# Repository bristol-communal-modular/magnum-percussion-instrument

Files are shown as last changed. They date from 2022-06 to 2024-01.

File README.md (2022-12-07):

# The Magnum Percussion Instrument

A drum synthesiser created by members of the Bristol Communal Modular group

## Description

Mostly combining bits from other open source schematics.

Specifically :-

* The Clacktronics Star Synare 3
* The Befaco Kickall

Many thanks to the people that designed those and made them open.

## Building

In the *build* folder there's an html BOM file, along with a CSV file that has part numbers for most components. Read the build.md file in there for more information. If you're reading this on GitHub and are unsure how to easily get these files, then [use this link](https://github.com/bristol-communal-modular/magnum-percussion-instrument/archive/refs/heads/main.zip)

## Spec

*Finish this*

### Power

30mA on +12v
30mA on -12v

Doesn't use 5v

## Contact

Come down the Bristol Hackspace on a Tuesday night to say hello.

## License

The Magnum Percussion Instrument is shared under an [Attribution-NonCommercial-ShareAlike 4.0 International License](https://creativecommons.org/licenses/by-nc-sa/4.0/)

This means that you can share the info here around, and transform or build upon the circuits and designs in here, as long as you share anything you do under the same license and give BCM a shout-out.

We don't license this for commercial purposes, but if you'd like to run a workshop with the Magnum or some variation of it, just get in contact and we can sort something out.
If you want to build a couple to sell to your mates then we're pretty fine with that as well.

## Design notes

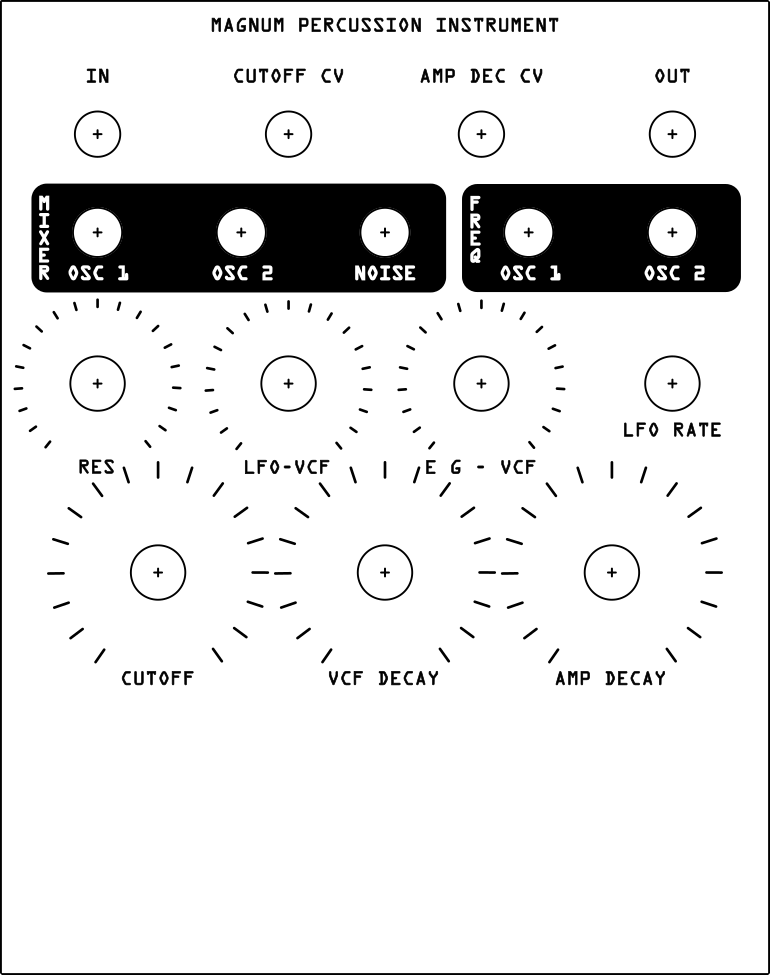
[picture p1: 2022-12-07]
docs/magnum-patch-notes-blank.png

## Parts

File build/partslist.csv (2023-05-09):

Description | References | Value | Quantity Per PCB | Spec | Tolerance | Voltage | Name
Diode | D1 D2 D5 D6 D7 D8 | 1N4148 | 6
Diode | D3 D4 | 1N5818 | 2
Resistor | R3 R4 R6 R7 R8 R11 R15 R20 R21 R27 R28 R30 R33 R43 R48 R49 R56 R57 R60 R66 R68 R69 | 100k | 22 |  | 1%
Resistor | R31 R32 R41 R42 R54 R55 R62 R64 R65 R67 | 220r | 10 |  | 1%
Resistor | R19 R22 R38 R47 R58 R70 R71 | 10k | 7 |  | 1%
Resistor | R12 R23 R36 R39 R40 R52 R53 | 22k | 7 |  | 1%
Resistor | R29 R51 R61 R63 | 470r | 4 |  | 1%
Resistor | R18 R24 R34 R44 | 1k | 4 |  | 1%
Resistor | R1 R5 R59 | 47k | 3 |  | 1%
Resistor | R17 R50 | 33k | 2 |  | 1%
Resistor | R2 R45 | 4k7 | 2 |  | 1%
Resistor | R25 | 150k | 1 |  | 1%
Resistor | R9 R26 | 220k | 2 |  | 1%
Resistor | R10 | 2k | 1 |  | 1%
Resistor | R14 | 120k | 1 |  | 1%
Resistor | R35 R46 | 47r | 2 |  | 1%
Resistor | R16 | 27k | 1 |  | 1%
Resistor | R37 | 6k8 | 1 |  | 1%
Resistor | R13 | 1m | 1 |  | 1%
Unpolarized capacitor | C4 C5 C8 C9 C11 C13 C22 C25 C26 C28 C31 C32 C34 C35 | 100nF | 14 | ceramic X7R | 5%
Polarized capacitor | C15 C17 C18 C20 C24 | 1uF | 5 | electrolytic | 20% | 50v
Polarized capacitor | C10 C14 C23 C36 | 10uF | 4 | electrolytic | 20% | 50v
Unpolarized capacitor | C21 C27 C30 C33 | 100pF | 4 | film polypropylene | 5%
Unpolarized capacitor | C2 C6 C7 | 22pF | 3 | ceramic C0G | 5%
Unpolarized capacitor | C12 C16 | 47nF | 2 | ceramic C0G | 5%
Unpolarized capacitor | C1 C19 | 10nF | 2 | ceramic C0G | 5%
Unpolarized capacitor | C3 | 220nF | 1 | ceramic X7R | 5%
Unpolarized capacitor | C29 | 1uF | 1 | electrolytic non polarised | 20% | 50v
IC | U4 U6 U7 | LM13700 | 3
IC | U1 U5 | TL074 | 2
IC | U3 | TL072 | 1
IC | U2 | CD4093 | 1
Transistor | Q1 Q2 Q4 | 2N3904 | 3
Transistor | Q3 Q5 Q6 | 2N3906 | 3
Trim-potentiometer | RV1 | 100k | 1 | single turn |  |  | Piezo Sensitivity
Trim-potentiometer | RV2 | 1mB | 1 | single turn
Piezo | MK1 | Piezo | 1 | 27mm
Header | J4 J5 | Conn_01x03_Header | 2 |  |  |  | Piezo Normal Output Level Select
Header | J6 | Conn_01x04_Header | 1 |  |  |  | Power Header Main
Socket | J2 | Conn_01x04_Socket | 1 |  |  |  | Power Header Ctrl
Socket | J1 | Conn_02x10_Socket | 1
Header | J7 | Conn_02x10_Header | 1
Jack | J8 J9 J10 J11 | Eurorack Mono Jack | 4 |  |  |  | Trig In Freq CV Decay CV Audio Out
Socket | J3 | Eurorack Power Small | 1
Potentiometer | RV3 RV4 RV5 | 100kA | 3 |  |  |  | OSC1 Level OSC2 Level Noise Level
Potentiometer | RV9 RV10 RV11 RV12 RV13 | 100kB | 5 |  |  |  | Filter LFO Mod Filter Env Mod Filter Freq Filter Env Decay Amp Env Decay
Potentiometer | RV6 RV7 | 1mA | 2 |  |  |  | OSC1 Freq OSC2 Freq
Potentiometer | RV8 | 50kB | 1 |  |  |  | Filter Res
Switch | SW1 | DPDT | 1 |  |  |  | OSC2 LFO

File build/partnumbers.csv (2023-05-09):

parttype | value | spec | quantity | info | order code | part number | mouser | farnell | other
diode | 1n4148 |  | 6 |  |  | 1n4148 | 512-1N4148
diode | 1n5818 |  | 2 |  |  | 1n5818 | 833-1N5818-TP
resistor | 100k | metal film | 22 |  |  | mfr50sfte52-100k | 603-MFR50SFTE52-100K
resistor | 220r | metal film | 10 |  |  | mfr50sfte52-220r | 603-MFR50SFTE52-220R
resistor | 10k | metal film | 7 |  |  | mfr50sfte52-10k | 603-MFR50SFTE52-10K
resistor | 22k | metal film | 7 |  |  | mfr50sfte52-22k | 603-MFR50SFTE52-22K
resistor | 470r | metal film | 4 |  |  | mfr-50sfrf52470r | 603-MFR-50SFRF52470R
resistor | 1k | metal film | 3 |  |  | mfr50sfte52-1k | 603-MFR50SFTE52-1K
resistor | 47k | metal film | 3 |  |  | mfr50sfte52-47k | 603-MFR50SFTE52-47K
resistor | 33k | metal film | 2 |  |  | mfr50sfte52-33k | 603-MFR50SFTE52-33K
resistor | 4k7 | metal film | 2 |  |  | mfr50sfte52-4k7 | 603-MFR50SFTE52-4K7
resistor | 220k | metal film | 2 |  |  | mfr50sfte52-220k | 603-MFR50SFTE52-220K
resistor | 150k | metal film | 1 |  |  | mfr50sfte52-150k | 603-MFR50SFTE52-150K
resistor | 2k | metal film | 1 |  |  | mfr50sfte52-2k | 603-MFR50SFTE52-2K
resistor | 120k | metal film | 1 |  |  | mfr50sfte52-120k | 603-MFR50SFTE52-120K
resistor | 47r | metal film | 1 |  |  | mfr50sfte52-47r | 603-MFR50SFTE52-47R
resistor | 27k | metal film | 1 |  |  | mfr50sfte52-27k | 603-MFR50SFTE52-27K
resistor | 6k8 | metal film | 1 |  |  | mfr50sfte52-6k8 | 603-MFR50SFTE52-6K8
resistor | 1m | metal film | 2 |  |  | mfr50sfte52-1m | 603-MFR50SFTE52-1M
capacitor | 100nf | ceramic x7r | 14 |  |  | k104k15x7rf53h5 | 594-K104K15X7RF53H5
capacitor | 1uf | electrolytic | 4 |  |  | uvr2a010mdd | 647-UVR2A010MDD
capacitor | 10uf | electrolytic | 4 |  |  | uvr1h100mdd | 647-UVR1H100MDD
capacitor | 100pf | film polypropylene | 4 |  |  | fkp2d001001d00jssd | 505-FKP2100/100/5
capacitor | 22pf | ceramic c0g | 3 |  |  | fg28c0g1h220jnt06 | 810-FG28C0G1H220JNT0
capacitor | 47nf | ceramic c0g | 2 |  |  | fg26c0g1h473jnt06 | 810-FG26C0G1H473JNT6
capacitor | 10nf | ceramic c0g | 2 |  |  | fg28c0g1h103jnt06 | 810-FG28C0G1H103JNT0
capacitor | 220nf | ceramic x7r | 1 |  |  | k224k20x7rf5uh5 | 594-K224K20X7RF5UH5
capacitor | 1uf | electrolytic non polarised | 1 |  |  | uvp1h010mdd | 647-UVP1H010MDD
opamp | lm13700 |  | 3 |  |  | lm13700n/nopb | 926-LM13700N/NOPB |  | thonk or anywhere else
opamp | tl074 |  | 2 |  |  | tl074cn | 595-TL074CN
opamp | tl072 |  | 1 |  |  | tl072ip | 595-TL072IP | 3117794 | thonk
logic | cd4093 |  | 1 |  |  | cd4093be | 595-CD4093BE
transistor | 2n3904 |  | 3 |  |  | 2n3904 | 512-2N3904BU
transistor | 2n3906 |  | 3 |  |  | 2n3906 | 512-2N3906BU
trimmer | 100kB | single turn | 1 |  |  | 3306p-1-104 | 652-3306P-1-104
trimmer | 1mB | single turn | 1 |  |  | 3306p-1-105 | 652-3306P-1-105
hardware | piezo | 27mm | 1 |  |  | ae-2746e-n1 | 253-AE2746EN1
switch | dpdt | on-on small pushbutton | 1 |  |  | mhps2285 | 642-MHPS2285 |  | hackspace
connector | mini jumper |  | 2 |  |  | SX1100-B | 806-SX1100-B
connector | eurorack power small |  | 1 |  |  | 61201021621 | 710-61201021621 |  | thonk
connector | DIP 8 IC socket |  | 2 |  |  | DILB8P-223TLF | 649-DILB8P223TLF |  | thonk
connector | DIP 14 IC socket |  | 2 |  |  | DILB14P-223TLF | 649-DILB14P-223TLF |  | thonk
connector | DIP 16 IC socket |  | 3 |  |  | DILB16P-223TLF | 649-DILB16P-223TLF |  | thonk
hardware | standoff | 11mm f-f | 2 |  |  | 970110321 | 710-970110321 |  | thonk
hardware | screw | m3 | 4
socket | eurorack mono jack |  | 4 |  |  | wqp-pj398sm |  |  | thonk
potentiometer | 100kb |  | 5 |  |  | rd901f-40-15k-b100k |  |  | thonk
potentiometer | 100ka |  | 3 |  |  | rd901f-40-15k-a100k |  |  | thonk
potentiometer | 1ma | trimpot | 2 |  |  | rd901f-40-15k-a1m |  |  | thonk
potentiometer | 50kb |  | 1 |  |  | rd901f-40-15k-b50k |  |  | thonk
connector | conn_02x10_header |  | 1 |  |  | tsw-110-14-t-d | 200-TSW11014TD |  | thonk
connector | conn_02x10_socket |  | 1 |  |  | ssq-110-01-t-d | 200-SSQ11001TD |  | thonk
connector | conn_01x04_header |  | 1 |  |  | tsw-110-14-t-d | 200-TSW11014TD |  | thonk
connector | conn_01x04_socket |  | 1 |  |  | ssq-104-01-t-s | 200-SSQ10401TS |  | thonk
connector | conn_01x03_header |  | 2 |  |  | tsw-103-14-t-s | 200-TSW10314TS |  | thonk

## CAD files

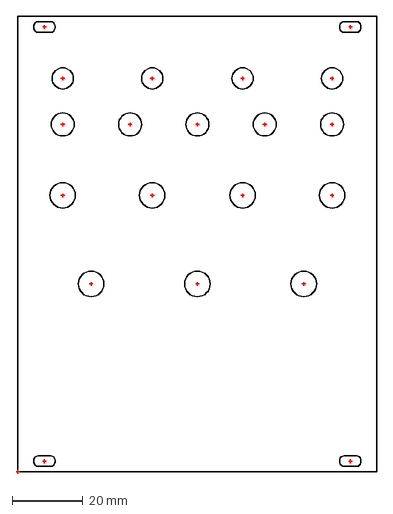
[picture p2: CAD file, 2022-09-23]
panel/panel-layout.dxf
101.8 x 129.0 mm

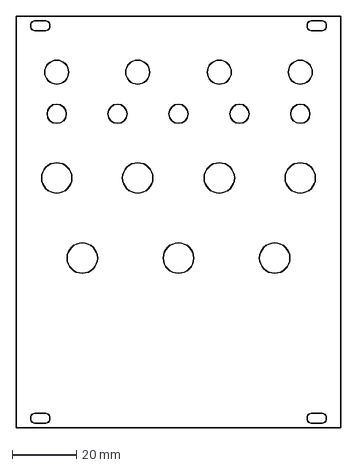
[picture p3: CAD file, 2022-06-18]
panel/panel.dxf
101.3 x 128.5 mm

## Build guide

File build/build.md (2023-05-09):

# Build

The build of the Magnum *should* be relatively straight forward. Just populate the boards, put them together, make sure the normalling and output level headers have jumpers, and then that should be everything.

That said, the following information will probably be useful.

## Extra Parts

There are a couple of parts that are required to build the magnum that aren't listed in the BOM.

* A cap for the DPDT push switch (no idea on part number yet sorry)
* Some red and black wire to connect the piezo to the board
* 4 M3 screws to use with the standoffs
* Some knobs for the controls
* A eurorack power cable

## Sourcing Parts

Most of the parts needed are pretty standard and can be found on Mouser, Farnell, Digikey, etc. There's a couple things worth noting.

Potentiometers are probably best to get from Thonk.

The LM13700 DIP chips are getting trickier to find as they've been End Of Life-d. [Thonk](https://www.thonk.co.uk/shop/lm13700/) has them, as do a few other smaller synth oriented shops.

The inter-board connectors can be found at mouser in the right sizes, but Thonk has cheaper alternatives if you're willing to cut them down. They're also good for the standoffs and various other bits.
[https://www.thonk.co.uk/shop/eurorack-diy-essentials/](https://www.thonk.co.uk/shop/eurorack-diy-essentials/)

The Cap on the DPDT switch being used has been tricky to find a part number for. Currently we're using the large number available at the Bristol Hackspace, but will need to figure something out eventually. There do seem to be plenty of suitable ones available on eBay. Have a search for "Self locking push button caps".

The piezo can be attached to the faceplate by soldering it onto the metal patch. Be careful when doing this, and when soldering wires onto the piezo discs as they can be quite delicate. Using flux is a good idea.

The *partnumbers.csv* file in this folder has partnumbers for most components, along with mouser order numbers and notes on what's probably better to get from Thonk.

## Part Choices

There are really only two places part choices are important.

* Reverse power protection diodes
* Capacitors

The protection diodes should ideally be schottky diodes with a low voltage drop.

Most of the capacitors are either ceramic or electrolytic, but the 100pf filter capacitors should be film. Good quality, metallized polypropylene is the best, but any decent quality film cap that fits will be fine.
There is one electrolytic capacitor that needs to be non-polarised (C16).

## Building

When soldering the boards, it's almost always easiest to start with the physically shortest components and then work upwards. In this case that would be :-

* diodes
* resistors
* DIP sockets
* ceramic capacitors
* transistors
* film capacitors
* electrolytic capacitors
* anything else

When soldering in the inter-board headers, it's a good idea to connect the pin and socket headers, carefully sandwich the boards together with them held in place, and ideally use the standoffs and screws to keep them together. Once that's done, solder the pins, and then *very carefully* pull the boards apart, trying not to bend any pins. Soldering the headers and sockets into the two boards separately will probably end up with them not lining up quite correctly.

Similarly, when soldering pots and jacks, insert them into the pcb, then put the faceplate on, make sure everything is lined up, and then lightly screw them into place to hold steady whilst you solder.

Finally, when soldering resistors and diodes in, it's often easier to solder them in from the front and then fixing up any sub-part joints from the back when trimming of leads. This avoids having the keep flipping the PCB over with parts in and trying to stop them falling out.

## Calibration

There are two trimmers that can be used for calibration.

### Piezo Sensitivity

RV1 which is situated on the control board and is accesible via the small hole in the PCB can be used to adjust the sensitivity of the piezo trigger circuit. If you find you have to hit the panel harder than you like, or the magnum triggers too easily, then this board can be used to adjust the responsiveness.

### Noise Level

The noise of the magnum is generated using transistor Q1, but because of the natural variance between parts it may be too quiet or too loud at maximum volume. RV2 allows adjusting this.

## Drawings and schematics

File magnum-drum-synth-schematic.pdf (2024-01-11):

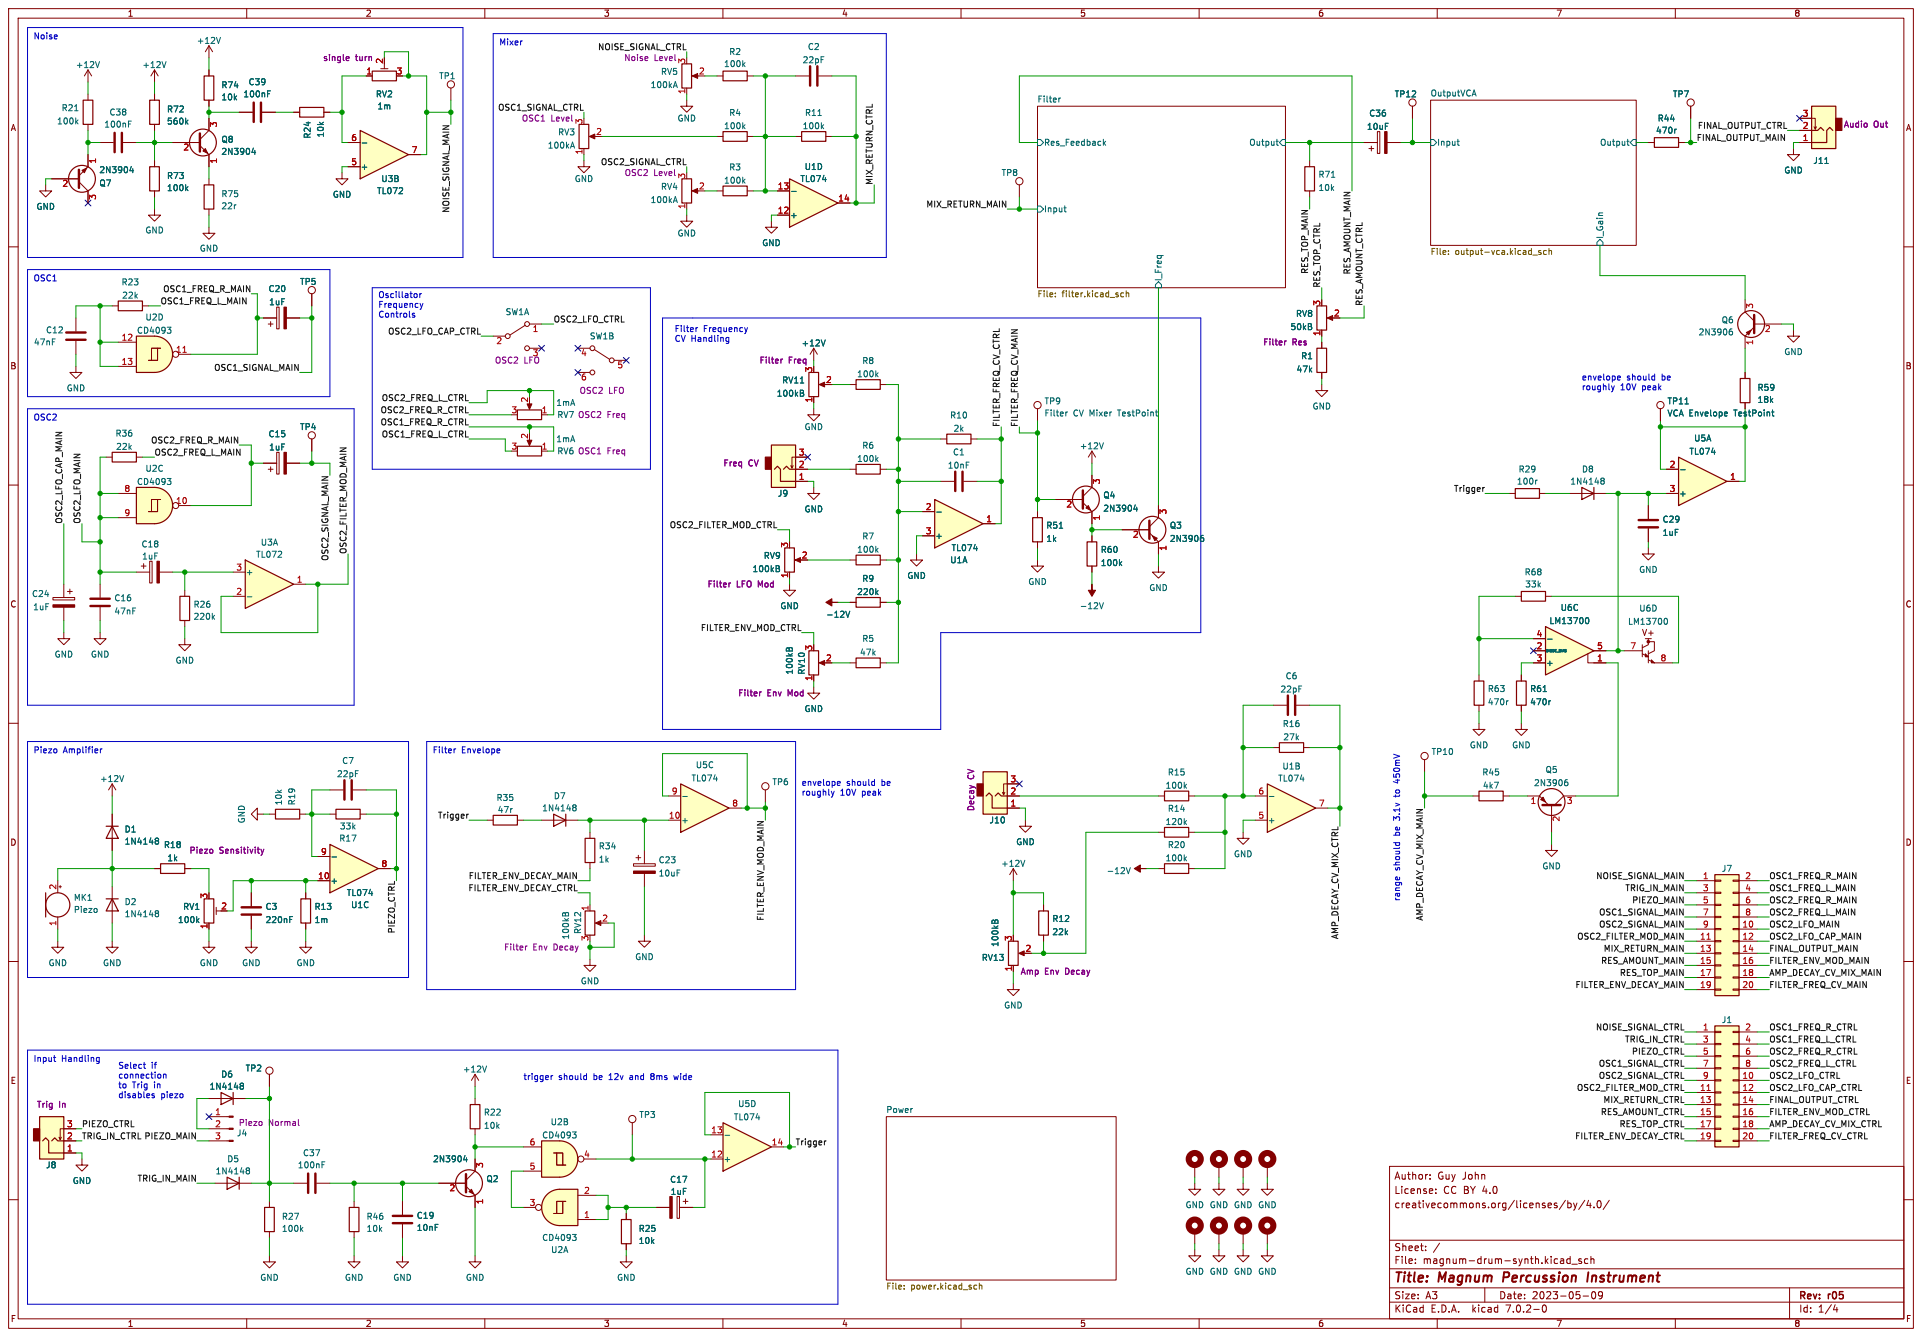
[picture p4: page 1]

roughly 10V peak Filter Envelope OSC2 OSC1 Noise

3 GND GND 100kB RV10 Filter Env Mod

trigger should be 12v and 8ms wide

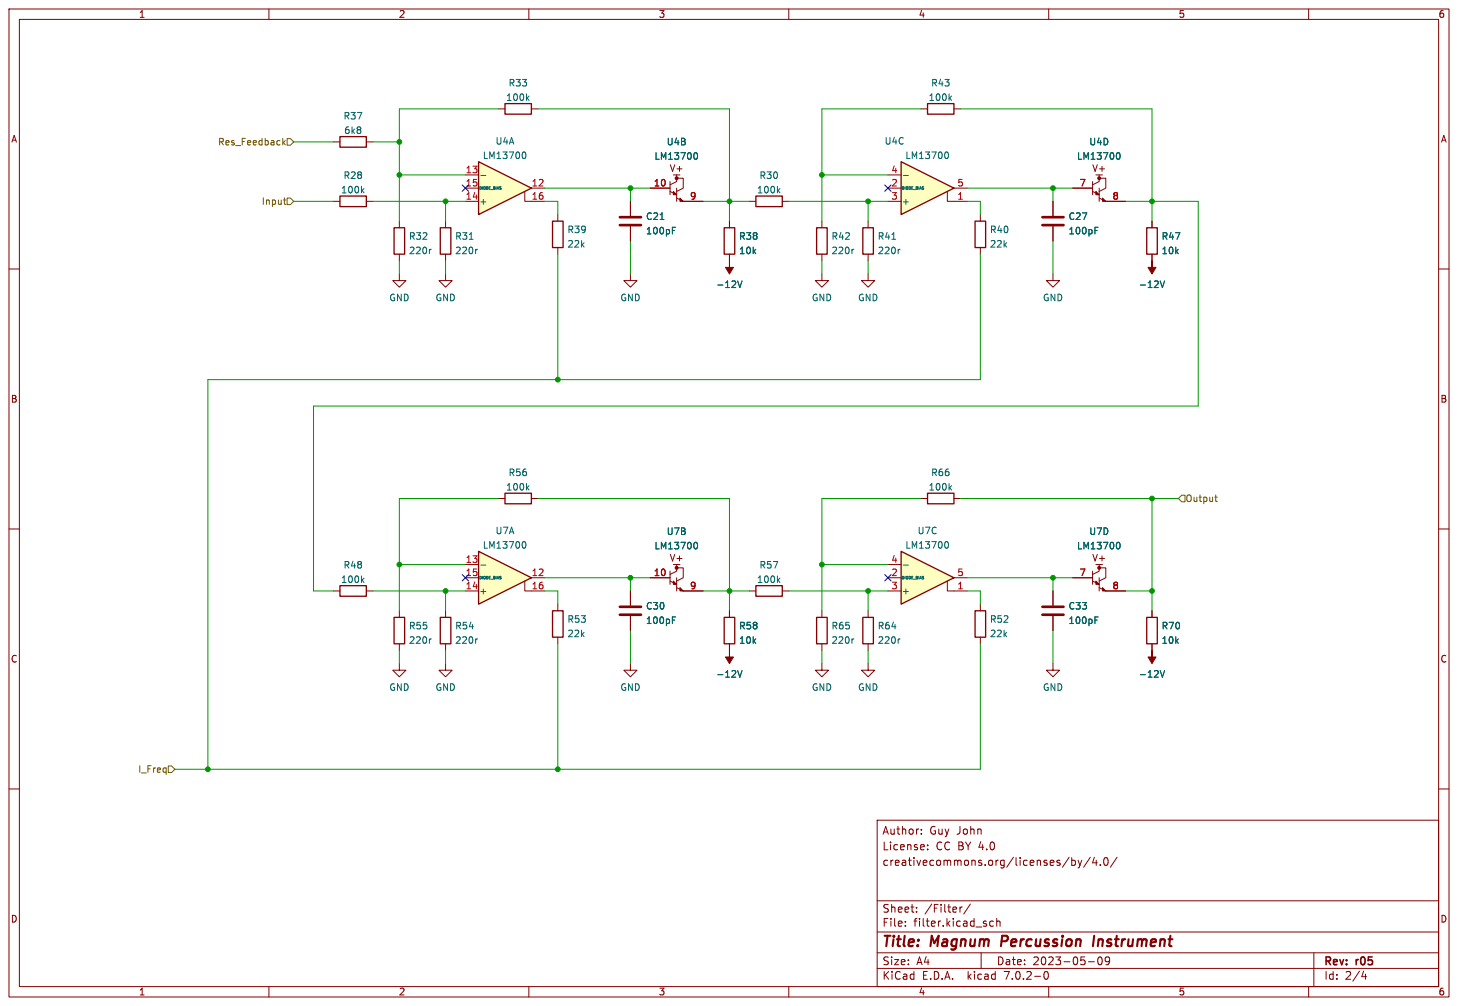
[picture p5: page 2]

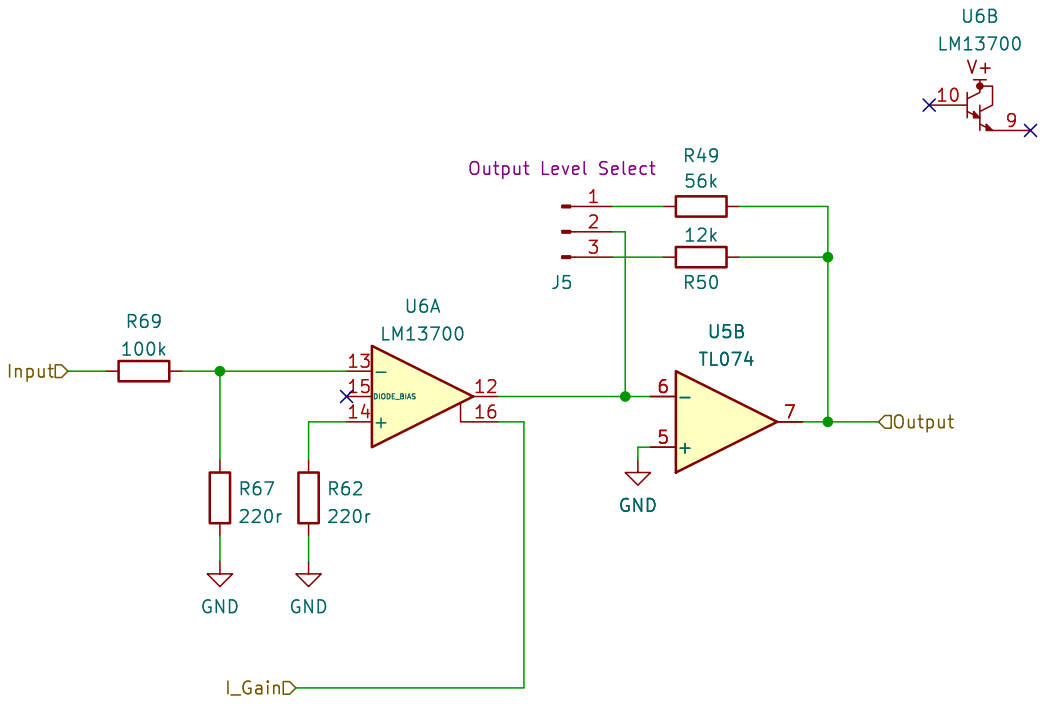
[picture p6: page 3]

Id: 3/4 Title: Magnum Percussion Instrument File: output-vca.kicad_sch Sheet: /OutputVCA/

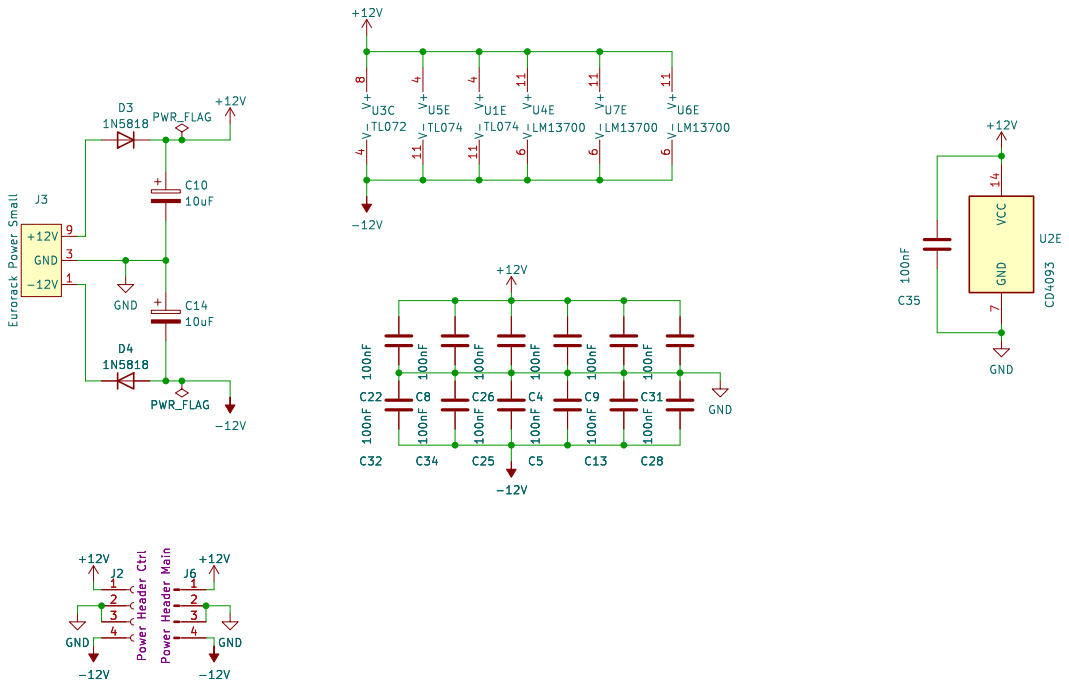
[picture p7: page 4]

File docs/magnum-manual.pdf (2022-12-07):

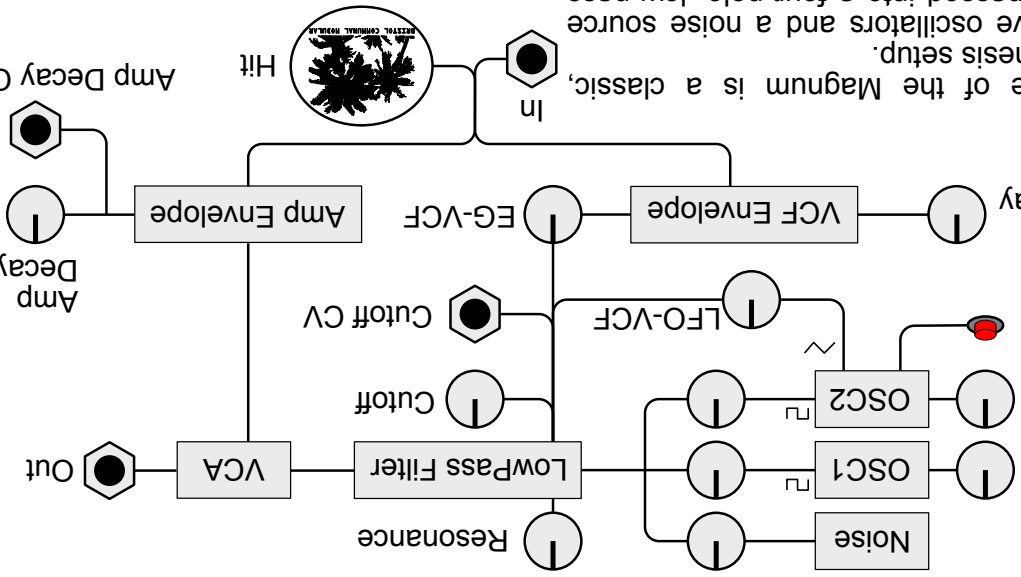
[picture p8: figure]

### Jumpers

### Power

There are two jumpers on the magnum which slightly change how it works.

The Output Level jumper sets the output to be either modular or line level. If you're using the magnum standalone then line level is a lower volume that may play better with other gear.

The piezo normalling jumper sets whether a jack plugged into the IN socket disconnects the piezo or not.

The Magnum needs a +12v and -12v dual supply, and draws about 30ma of power on each rail. This should easily be provided by your eurorack system.

If you have one of the separate enclosures then there should be a small power board in the bottom that allows it to run of a 12 volt wall wart adapter. If you use a different adapter from the original one then make sure it's a centre positive, 12 volt DC one. Otherwise you might make some magic smoke.

The magnum project is fully open-source and licensed under a CC BY-NC-SA 4.0 International License.
You can find all the files for it and anything else we do at: https://github.com/bristol-communal-modular

### The Magnum P.I. is our recreation of the Star Synare 3, updated to work well in a eurorack

modular system or as a standalone instrument.

The synare was a staple in a lot of post punk,

### dub and disco production in the 70s through the

80s.

### You can hear it in loads of tunes by Joy

Division, Scientist, The Cure, Depeche Mode,

### the iconic Jah Shaka sound system scene in the film Babylon(1980) and a tonne of disco tunes too. Once you start noticing the Synare

hits you won’t stop finding them.

### We've found that the Magnum has some pretty interesting sounds it can make beyond just the standard disco pew and weird snare, so it's worth

spending time tweaking it.

### Thanks

The Brunswick club for helping support us.
Thonk and Pusherman for donations.
Clacktronics for the synare schematic that started this. Befaco for open-sourcing their schematics so that we could learn from them.

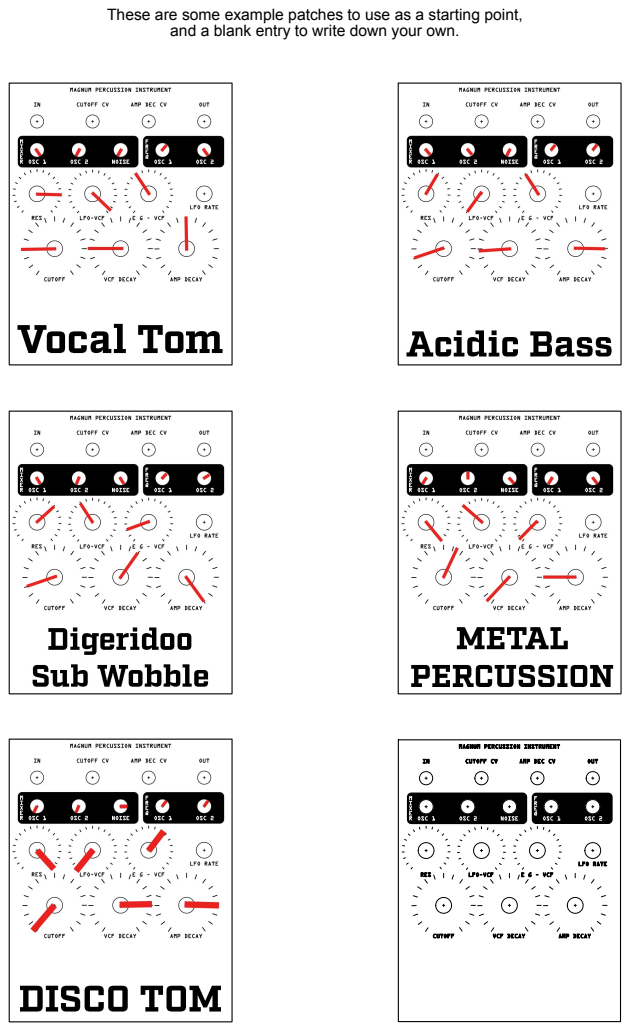
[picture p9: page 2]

These are some example patches to use as a starting point,

and a blank entry to write down your own.

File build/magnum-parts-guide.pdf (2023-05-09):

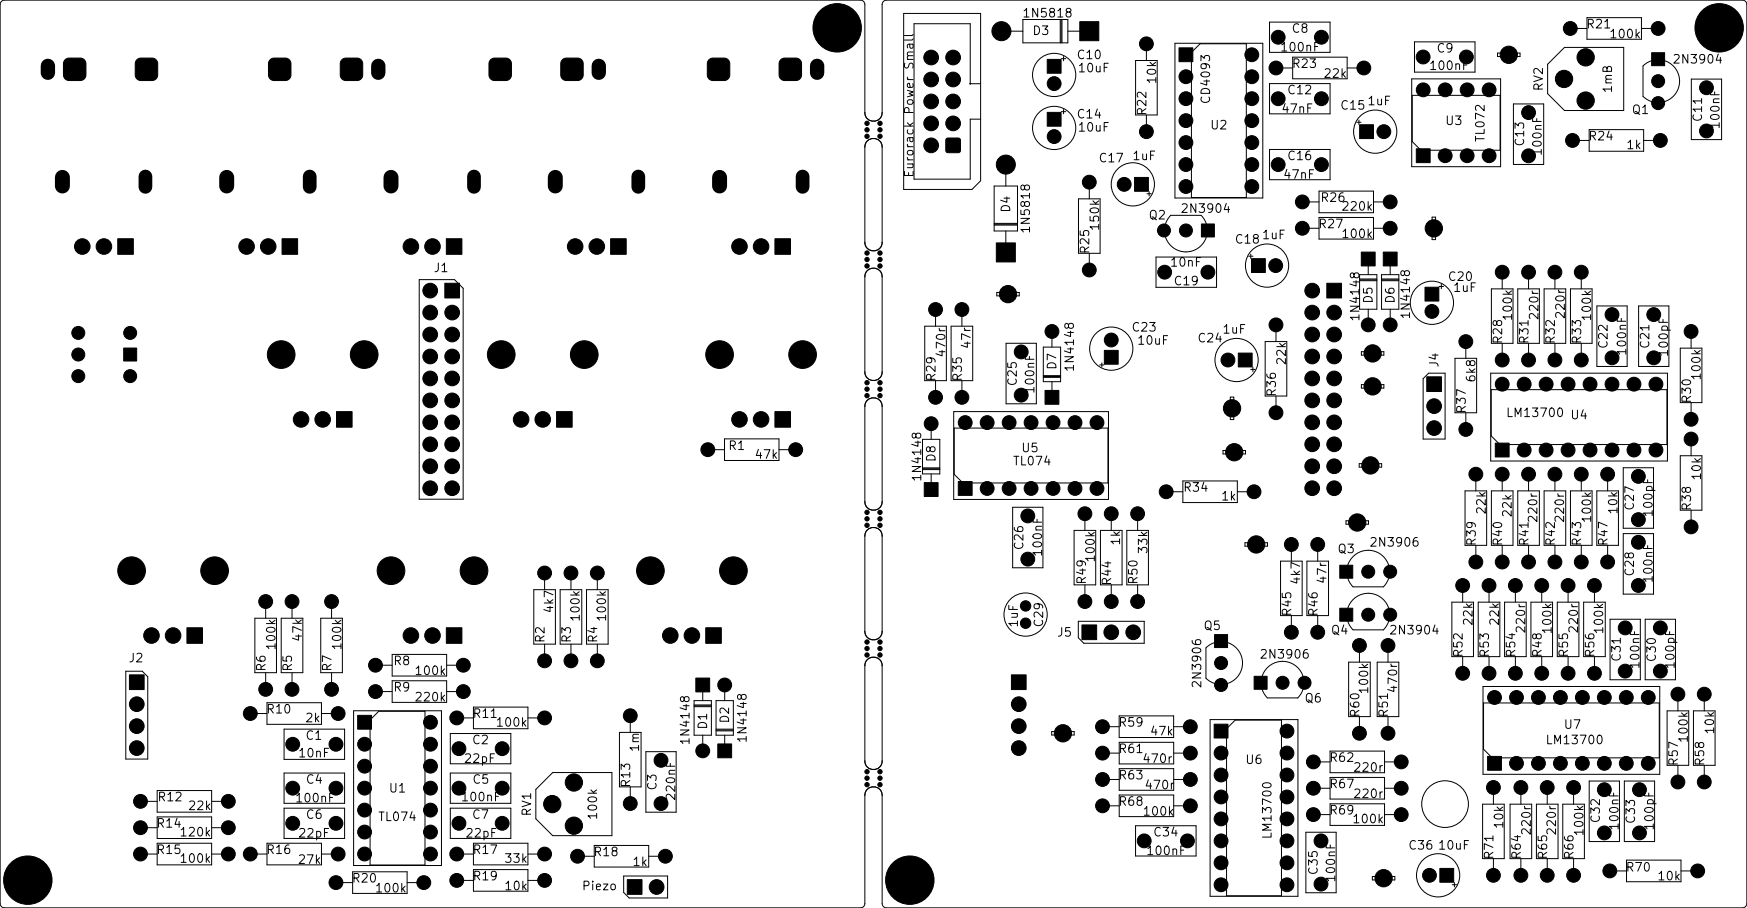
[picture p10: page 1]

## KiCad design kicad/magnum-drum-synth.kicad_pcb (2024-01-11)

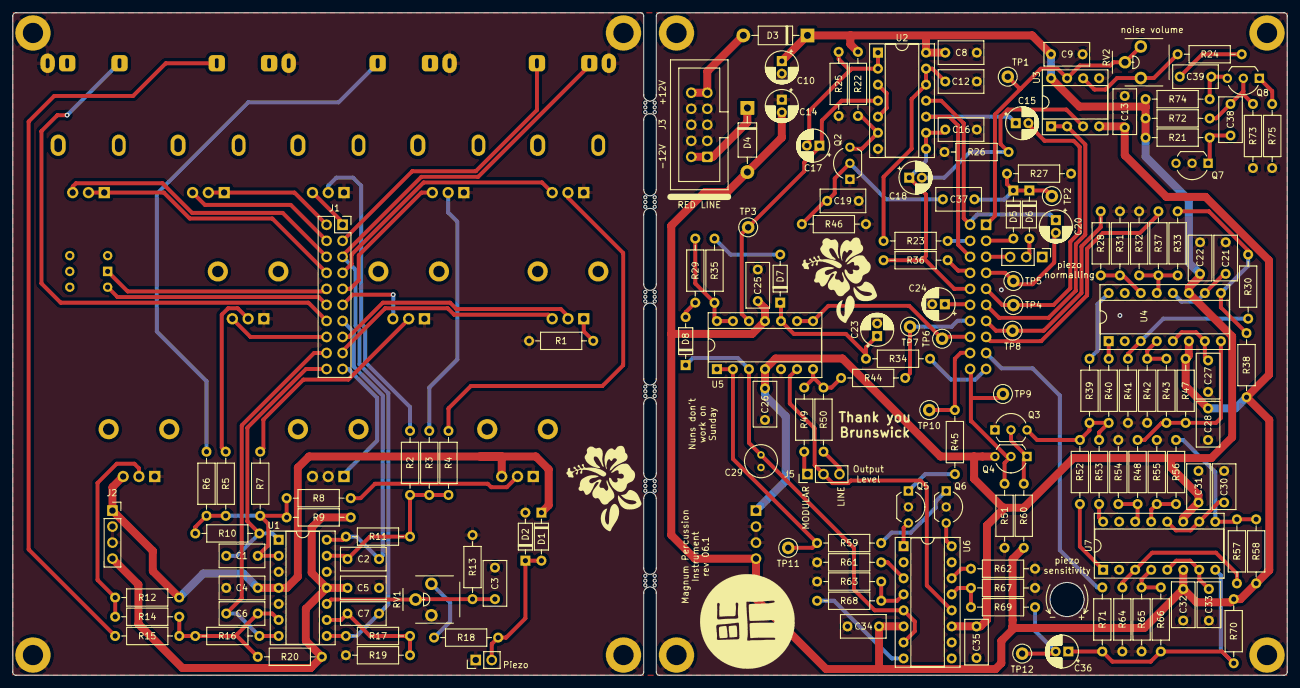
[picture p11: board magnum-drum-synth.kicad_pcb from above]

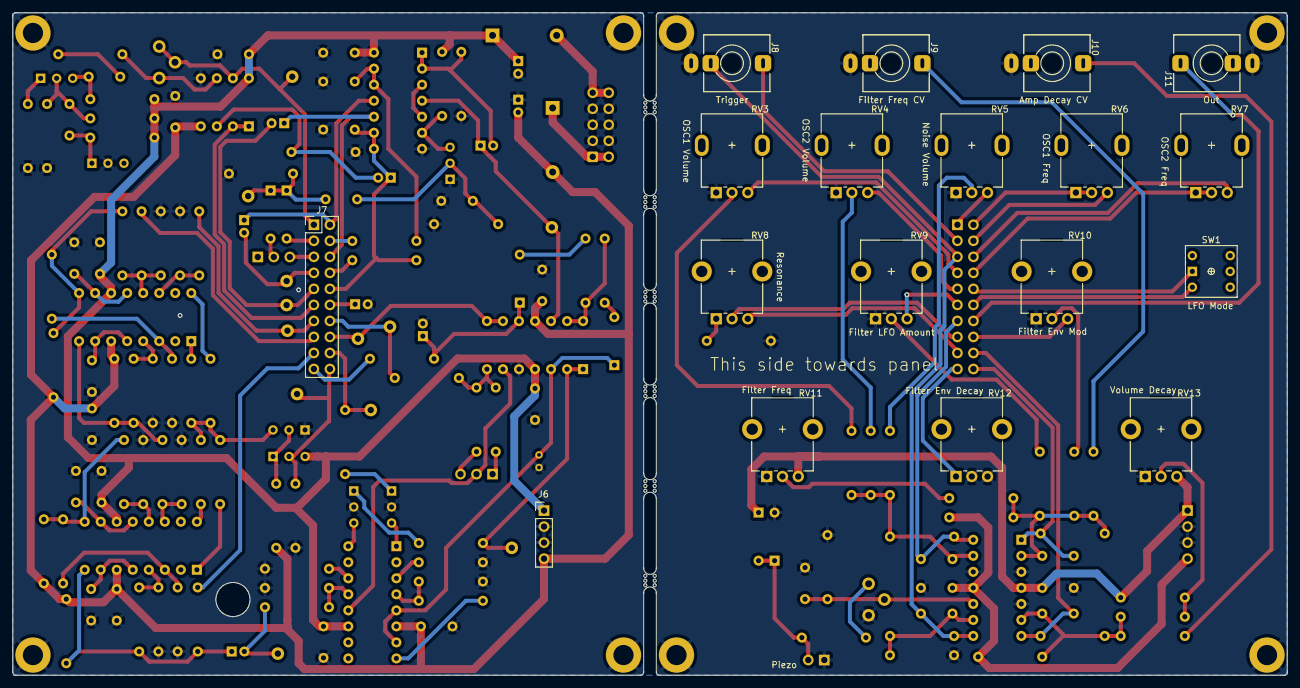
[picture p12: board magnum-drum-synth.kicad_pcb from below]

Board: 2 copper layers, 202.0 x 105.0 mm, 188 parts (18 on the bottom side), 119 nets.

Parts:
C1, C19: 10nF; C_Rect_L7.0mm_W3.5mm_P5.00mm
C2, C6, C7: 22pF; C_Rect_L7.0mm_W3.5mm_P5.00mm
C3: 220nF; C_Rect_L7.0mm_W3.5mm_P5.00mm
C4, C5, C8, C9, C13, C22, C25, C26, C28, C31, C32, C34, C35, C37, C38, C39: 100nF; C_Rect_L7.0mm_W3.5mm_P5.00mm
C10, C14, C23, C36: 10uF; CP_Radial_D5.0mm_P2.00mm
C12, C16: 47nF; C_Rect_L7.0mm_W3.5mm_P5.00mm
C15, C17, C18, C20, C24: 1uF; CP_Radial_D5.0mm_P2.00mm
C21, C27, C30, C33: 100pF; C_Rect_L7.0mm_W3.5mm_P5.00mm
C29: 1uF; C_Radial_D5.0mm_H5.0mm_P2.00mm
D1, D2, D5, D6, D7, D8: 1N4148; D_DO-35_SOD27_P7.62mm_Horizontal
D3, D4: 1N5818; D_DO-41_SOD81_P10.16mm_Horizontal
H1, H2, H9, H10, H13, H14, H15, H16: MountingHole_Pad; MountingHole_3.2mm_M3_DIN965_Pad
H3, H4, H5, H6, H7, H8: MouseBite; mouse-bite-2mm-slot
J1: Conn_02x10_Odd_Even; PinSocket_2x10_P2.54mm_Vertical
J2: Conn_01x04_Socket; PinSocket_1x04_P2.54mm_Vertical
J3: locked; Eurorack_PowerHeader_2x05_P2.54mm_Shrouded
J4, J5: Conn_01x03_Header; PinHeader_1x03_P2.54mm_Vertical
J6: Conn_01x04_Header; PinHeader_1x04_P2.54mm_Vertical
J7: Conn_02x10_Odd_Even; PinHeader_2x10_P2.54mm_Vertical
J8, J9, J10, J11: Eurorack Mono Jack; Jack_3.5mm_QingPu_WQP-PJ398SM_Vertical
MK1: Piezo; PinHeader_1x02_P2.54mm_Vertical
Q2, Q4, Q7, Q8: 2N3904; TO-92_Inline_Wide
Q3, Q5, Q6: 2N3906; TO-92_Inline_Wide
R1, R5: 47k; R_Axial_DIN0207_L6.3mm_D2.5mm_P10.16mm_Horizontal
R2, R3, R4, R6, R7, R8, R11, R15, R20, R21, R27, R28, R30, R33, R43, R48, R56, R57, R60, R66, R69, R73: 100k; R_Axial_DIN0207_L6.3mm_D2.5mm_P10.16mm_Horizontal
R9, R26: 220k; R_Axial_DIN0207_L6.3mm_D2.5mm_P10.16mm_Horizontal
R10: 2k; R_Axial_DIN0207_L6.3mm_D2.5mm_P10.16mm_Horizontal
R12, R23, R36, R39, R40, R52, R53: 22k; R_Axial_DIN0207_L6.3mm_D2.5mm_P10.16mm_Horizontal
R13: 1m; R_Axial_DIN0207_L6.3mm_D2.5mm_P10.16mm_Horizontal
R14: 120k; R_Axial_DIN0207_L6.3mm_D2.5mm_P10.16mm_Horizontal
R16: 27k; R_Axial_DIN0207_L6.3mm_D2.5mm_P10.16mm_Horizontal
R17, R68: 33k; R_Axial_DIN0207_L6.3mm_D2.5mm_P10.16mm_Horizontal
R18, R34, R51: 1k; R_Axial_DIN0207_L6.3mm_D2.5mm_P10.16mm_Horizontal
R19, R22, R24, R25, R38, R46, R47, R58, R70, R71, R74: 10k; R_Axial_DIN0207_L6.3mm_D2.5mm_P10.16mm_Horizontal
R29: 100r; R_Axial_DIN0207_L6.3mm_D2.5mm_P10.16mm_Horizontal
R31, R32, R41, R42, R54, R55, R62, R64, R65, R67: 220r; R_Axial_DIN0207_L6.3mm_D2.5mm_P10.16mm_Horizontal
R35: 47r; R_Axial_DIN0207_L6.3mm_D2.5mm_P10.16mm_Horizontal
R37: 6k8; R_Axial_DIN0207_L6.3mm_D2.5mm_P10.16mm_Horizontal
R44, R61, R63: 470r; R_Axial_DIN0207_L6.3mm_D2.5mm_P10.16mm_Horizontal
R45: 4k7; R_Axial_DIN0207_L6.3mm_D2.5mm_P10.16mm_Horizontal
R49: 56k; R_Axial_DIN0207_L6.3mm_D2.5mm_P10.16mm_Horizontal
R50: 12k; R_Axial_DIN0207_L6.3mm_D2.5mm_P10.16mm_Horizontal
R59: 18k; R_Axial_DIN0207_L6.3mm_D2.5mm_P10.16mm_Horizontal
R72: 560k; R_Axial_DIN0207_L6.3mm_D2.5mm_P10.16mm_Horizontal
R75: 22r; R_Axial_DIN0207_L6.3mm_D2.5mm_P10.16mm_Horizontal
RV1: 100k; Potentiometer_THT_Bourns_3306P_Vertical
RV2: 1m; Potentiometer_THT_Bourns_3306P_Vertical
RV3, RV4, RV5: 100kA; Potentiometer_Song_Huei_R0904N_Single_Vertical
RV6, RV7: 1mA; Potentiometer_Song_Huei_R0904N_Single_Vertical
RV8: 50kB; Potentiometer_Alpha_RD901F-40-00D_Single_Vertical_CircularH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
RV9, RV10, RV11, RV12, RV13: 100kB; Potentiometer_Alpha_RD901F-40-00D_Single_Vertical_CircularH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
Ref**1: Val**; BCM_Logo_small_15mmx15mm
SW1: DPDT; SW_PUSH_2P2T_8mm_Apem_MHPS2285
TP1: Noise TestPoint; TestPoint_Loop_D2.50mm_Drill1.0mm_LowProfile
TP2: Trigger TestPoint; TestPoint_Loop_D2.50mm_Drill1.0mm_LowProfile
TP3, TP10: Schmitt Trigger TestPoint; TestPoint_Loop_D2.50mm_Drill1.0mm_LowProfile
TP4: OSC2 TestPoint; TestPoint_Loop_D2.50mm_Drill1.0mm_LowProfile
TP5: OSC1 TestPoint; TestPoint_Loop_D2.50mm_Drill1.0mm_LowProfile
TP6: Filter Envelope TestPoint; TestPoint_Loop_D2.50mm_Drill1.0mm_LowProfile
TP7: Final Output TestPoint; TestPoint_Loop_D2.50mm_Drill1.0mm_LowProfile
TP8: Mixer TestPoint; TestPoint_Loop_D2.50mm_Drill1.0mm_LowProfile
TP9: Filter CV Mixer TestPoint; TestPoint_Loop_D2.50mm_Drill1.0mm_LowProfile
TP11: VCA Envelope TestPoint; TestPoint_Loop_D2.50mm_Drill1.0mm_LowProfile
TP12: Filter Output TestPoint; TestPoint_Loop_D2.50mm_Drill1.0mm_LowProfile
U1, U5: TL074; DIP-14_W7.62mm_Socket
U2: CD4093; DIP-14_W7.62mm_Socket
U3: TL072; DIP-8_W7.62mm_Socket
U4, U6, U7: LM13700; DIP-16_W7.62mm_Socket

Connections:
+12V: C4.1, C8.1, C9.1, C10.1, C22.1, C26.1, C31.1, C35.1, D1.1 (K), D3.1 (K), J2.1, J6.1, Q4.3 (C), R12.2, R21.1, R22.1, R72.2, R74.2, RV11.3, RV13.3, U1.4 (V+), U2.14 (VCC), U3.8 (V+), U4.11 (V+), U5.4 (V+), U6.11 (V+), U7.11 (V+)
-12V: C5.2, C13.2, C14.2, C25.2, C28.2, C32.2, C34.2, D4.2 (A), J2.4, J6.4, R9.1, R20.1, R38.2, R47.2, R58.2, R60.1, R70.2, U1.11 (V-), U3.4 (V-), U4.6 (V-), U5.11 (V-), U6.6 (V-), U7.6 (V-)
/AMP_DECAY_CV_MIX_CTRL: C6.2, J1.18, R16.2, U1.7
/AMP_DECAY_CV_MIX_MAIN: J7.18, R45.1, TP10.1
/FILTER_ENV_DECAY_CTRL: J1.19, RV12.1
/FILTER_ENV_DECAY_MAIN: J7.19, R34.2
/FILTER_ENV_MOD_CTRL: J1.16, RV10.3
/FILTER_ENV_MOD_MAIN: J7.16, TP6.1, U5.8, U5.9 (-)
/FILTER_FREQ_CV_CTRL: C1.2, J1.20, R10.2, U1.1
/FILTER_FREQ_CV_MAIN: J7.20, Q4.2 (B), R51.1, TP9.1
/FINAL_OUTPUT_CTRL: J1.14, J11.2 (Tip)
/FINAL_OUTPUT_MAIN: J7.14, R44.2, TP7.1
/Filter/I_Freq: Q3.3 (C), R39.2, R40.2, R52.2, R53.2
/Filter/Output: C36.1, R66.2, R70.1, R71.1, U7.8
/MIX_RETURN_CTRL: C2.2, J1.13, R11.2, U1.14
/MIX_RETURN_MAIN: J7.13, R28.1, TP8.1
/NOISE_SIGNAL_CTRL: J1.1, RV5.3
/NOISE_SIGNAL_MAIN: J7.1, RV2.2, RV2.3, TP1.1, U3.7
/OSC1_FREQ_L_CTRL: J1.4, RV6.3
/OSC1_FREQ_L_MAIN: J7.4, R23.2
/OSC1_FREQ_R_CTRL: J1.2, RV6.1, RV6.2
/OSC1_FREQ_R_MAIN: C20.1, J7.2, U2.11
/OSC1_SIGNAL_CTRL: J1.7, RV3.3
/OSC1_SIGNAL_MAIN: C20.2, J7.7, TP5.1
/OSC2_FILTER_MOD_CTRL: J1.11, RV9.3
/OSC2_FILTER_MOD_MAIN: J7.11, U3.1, U3.2 (-)
/OSC2_FREQ_L_CTRL: J1.8, RV7.1, RV7.2
/OSC2_FREQ_L_MAIN: J7.8, R36.2
/OSC2_FREQ_R_CTRL: J1.6, RV7.3
/OSC2_FREQ_R_MAIN: C15.1, J7.6, U2.10
/OSC2_LFO_CAP_CTRL: J1.12, SW1.2 (B)
/OSC2_LFO_CAP_MAIN: C24.1, J7.12
/OSC2_LFO_CTRL: J1.10, SW1.1 (A)
/OSC2_LFO_MAIN: C16.1, C18.1, J7.10, R36.1, U2.8, U2.9
/OSC2_SIGNAL_CTRL: J1.9, RV4.3
/OSC2_SIGNAL_MAIN: C15.2, J7.9, TP4.1
/OutputVCA/I_Gain: Q6.3 (C), U6.16
/OutputVCA/Input: C36.2, R69.1, TP12.1
/OutputVCA/Output: R44.1, R49.2, R50.2, U5.7
/PIEZO_CTRL: C7.2, J1.5, J8.3 (Tip_normalize), R17.1, U1.8
/PIEZO_MAIN: J4.3, J7.5
/RES_AMOUNT_CTRL: J1.15, RV8.2
/RES_AMOUNT_MAIN: J7.15, R37.1
/RES_TOP_CTRL: J1.17, RV8.3
/RES_TOP_MAIN: J7.17, R71.2
/TRIG_IN_CTRL: J1.3, J8.2 (Tip)
/TRIG_IN_MAIN: D5.2 (A), J7.3
/Trigger: R29.1, R35.1, U5.13 (-), U5.14
GND: C3.1, C4.2, C5.1, C8.2, C9.2, C10.2, C12.1, C13.1, C14.1, C16.2, C19.1, C21.1, C22.2, C23.2, C24.2, C25.1, C26.2, C27.1, C28.1, C29.2, C30.1, C31.2, C32.1, C33.1, C34.1, C35.2, D2.2 (A), H1.1, H2.1, H9.1, H10.1, H13.1, H14.1, H15.1, H16.1, J2.2, J2.3, J3.3 (GND), J3.4 (GND), J3.5 (GND), J3.6 (GND), J3.7 (GND), J3.8 (GND), J6.2, J6.3, J8.1 (Sleeve), J9.1 (Sleeve), J10.1 (Sleeve), J11.1 (Sleeve), MK1.1 (-), Q2.1 (E), Q3.1 (E), Q5.2 (B), Q6.2 (B), Q7.2 (B), R1.2, R13.2, R19.1, R25.2, R26.1, R27.1, R31.2, R32.2, R41.2, R42.2, R46.2, R51.2, R54.2, R55.2, R61.1, R62.2, R63.1, R64.2, R65.2, R67.2, R73.1, R75.1, RV1.1, RV3.1, RV4.1, RV5.1, RV9.1, RV10.1, RV11.1, RV12.2, RV12.3, RV13.1, U1.3 (+), U1.5 (+), U1.12 (+), U2.7 (GND), U3.5 (+), U5.5 (+)
unnamed: C12.2, R23.1, U2.12, U2.13
unnamed: C17.2, R25.1, U2.1, U2.2
unnamed: C21.2, U4.10, U4.12
unnamed: C27.2, U4.5, U4.7
unnamed: C30.2, U7.10, U7.12
unnamed: C33.2, U7.5, U7.7
unnamed: C39.2, R24.1
unnamed: D1.2 (A), D2.1 (K), MK1.2 (+), R18.1
unnamed: D3.2 (A), J3.9 (+12V), J3.10 (+12V)
unnamed: D4.1 (K), J3.1 (-12V), J3.2 (-12V)
unnamed: C37.2, D5.1 (K), D6.1 (K), R27.2, TP2.1
unnamed: D6.2 (A), J4.2
unnamed: D7.2 (A), R35.2
unnamed: C23.1, D7.1 (K), R34.1, U5.10 (+)
unnamed: D8.2 (A), R29.2
unnamed: C29.1, D8.1 (K), U5.3 (+), U6.5, U6.7
unnamed: J5.1, R49.1
unnamed: J5.2, U5.6 (-), U6.12
unnamed: J5.3, R50.1
unnamed: J9.2 (Tip), R6.1
unnamed: J10.2 (Tip), R15.1
unnamed: C19.2, C37.1, Q2.2 (B), R46.1
unnamed: Q2.3 (C), R22.2, U2.6
unnamed: Q3.2 (B), Q4.1 (E), R60.2
unnamed: Q5.3 (C), U6.1
unnamed: Q5.1 (E), R45.2
unnamed: Q6.1 (E), R59.2
unnamed: C38.1, Q7.1 (E), R21.2
unnamed: C38.2, Q8.2 (B), R72.1, R73.2
unnamed: C39.1, Q8.3 (C), R74.1
unnamed: Q8.1 (E), R75.2
unnamed: R1.1, RV8.1
unnamed: R2.1, RV5.2
unnamed: R3.1, RV4.2
unnamed: R4.1, RV3.2
unnamed: R5.1, RV10.2
unnamed: R7.1, RV9.2
unnamed: R8.1, RV11.2
unnamed: R12.1, R14.2, RV13.2
unnamed: R18.2, RV1.3
unnamed: R30.1, R33.2, R38.1, U4.9
unnamed: R39.1, U4.16
unnamed: R40.1, U4.1
unnamed: R43.2, R47.1, R48.1, U4.8
unnamed: R52.1, U7.1
unnamed: R53.1, U7.16
unnamed: R56.2, R57.1, R58.1, U7.9
unnamed: R68.2, U6.8
unnamed: C1.1, R5.2, R6.2, R7.2, R8.2, R9.2, R10.1, U1.2 (-)
unnamed: C6.1, R14.1, R15.2, R16.1, R20.2, U1.6 (-)
unnamed: C3.2, R13.1, RV1.2, U1.10 (+)
unnamed: C7.1, R17.2, R19.2, U1.9 (-)
unnamed: C2.1, R2.2, R3.2, R4.2, R11.1, U1.13 (-)
unnamed: U2.3, U2.5
unnamed: C18.2, R26.2, U3.3 (+)
unnamed: R24.2, RV2.1, U3.6 (-)
unnamed: R28.2, R31.1, U4.14 (+)
unnamed: R32.1, R33.1, R37.2, U4.13 (-)
unnamed: R30.2, R41.1, U4.3 (+)
unnamed: R42.1, R43.1, U4.4 (-)
unnamed: R59.1, TP11.1, U5.1, U5.2 (-)
unnamed: C17.1, TP3.1, U2.4, U5.12 (+)
unnamed: R62.1, U6.14 (+)
unnamed: R67.1, R69.2, U6.13 (-)
unnamed: R61.2, U6.3 (+)
unnamed: R63.2, R68.1, U6.4 (-)
unnamed: R48.2, R54.1, U7.14 (+)
unnamed: R55.1, R56.1, U7.13 (-)
unnamed: R57.2, R64.1, U7.3 (+)
unnamed: R65.1, R66.1, U7.4 (-)

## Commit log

2022-04-04 Updating schematic some more
    [bcm-drum-synth.kicad_sch]
2022-04-04 Adding some info to schematic
    [bcm-drum-synth.kicad_sch]
2022-04-11 Rev 1
    [bcm-drum-synth-B_Cu.gbl, bcm-drum-synth-B_Mask.gbs, bcm-drum-synth-B_Silkscreen.gbo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]
2022-04-11 Changing name of project
    [bcm-drum-synth.sch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]
2022-04-11 Update schematic
    [magnum-drum-synth.kicad_sch]
2022-05-14 Creating rev02
    [filter.kicad_sch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]
2022-06-18 Updating after tweaks and project improvements
    [filter.kicad_sch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]
2022-06-26 Update BOM generation config
2022-06-26 Further tweaks and layout improvements
    [filter.kicad_sch, magnum-drum-synth.kicad_sch, output-vca.kicad_sch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]
2022-06-29 Finalising rev3
    [magnum-drum-synth-B_Cu.gbl, magnum-drum-synth-B_Mask.gbs, magnum-drum-synth-B_Silkscreen.gbo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]
2022-06-29 organising folders
    [filter.kicad_sch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]
2022-07-19 Tweaking schematic and bom values
    [magnum-drum-synth.kicad_sch, output-vca.kicad_sch, power.kicad_sch]
2022-07-19 Adding partnumbers csv
    [partnumbers.csv]
2022-08-31 Update front panel with new design
    [magnum-front-panel-B_Cu.gbl, magnum-front-panel-B_Mask.gbs, magnum-front-panel-B_Silkscreen.gbo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]
2022-08-31 Adding inkscape svg file for pcb panel layers
2022-09-23 Adding files for next revision of front panel
    [magnum-drum-synth.kicad_pcb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]
2022-10-16 Final tweaks to rev 4
    [filter.kicad_sch, magnum-drum-synth.kicad_sch, output-vca.kicad_sch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]
2022-10-16 replotting rev4 gerbers
    [magnum-drum-synth-B_Cu.gbl, magnum-drum-synth-B_Mask.gbs, magnum-drum-synth-B_Silkscreen.gbo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]
2022-10-16 Final export of everything for rev4
    [magnum-drum-synth-B_Cu.gbl, magnum-drum-synth-B_Mask.gbs, magnum-drum-synth-B_Silkscreen.gbo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]
2022-10-17 Updating partnumbers and build info
    [partnumbers.csv]
2022-12-11 Adding partslist csv
    [partslist.csv]
2022-12-23 Fixing trigger piezo normalling
    [magnum-drum-synth.kicad_sch]
2022-12-23 Rejigging interconnects
    [magnum-drum-synth.kicad_sch]
2022-12-23 Moving mixer opamp to front board
    [magnum-drum-synth.kicad_sch, power.kicad_sch]
2022-12-23 Tweaking silkscreen
2022-12-23 Move decay env CV summing to front board
    [magnum-drum-synth.kicad_sch]
2022-12-24 slimlining opamp count and more moving around
    [magnum-drum-synth.kicad_sch, output-vca.kicad_sch, power.kicad_sch]
2023-05-08 Final fixes and tweaks (hopefully)
    [magnum-drum-synth.kicad_sch, output-vca.kicad_sch, power.kicad_sch]
2023-05-08 Updating layout text for better soldering guide
2023-05-08 geographically reannotate all the parts
    [filter.kicad_sch, magnum-drum-synth.kicad_sch, output-vca.kicad_sch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]
2023-05-09 Fixing power header in wrong place
2023-05-09 Final tweaks to PCB
2023-05-09 Generating gerbers for rev5
    [magnum-drum-synth-B_Cu.gbl, magnum-drum-synth-B_Mask.gbs, magnum-drum-synth-B_Silkscreen.gbo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]
2023-05-09 remember to update schematic rev to r05
    [filter.kicad_sch, magnum-drum-synth.kicad_sch, output-vca.kicad_sch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]
2023-05-09 recreating schematic
2023-05-09 Update boms and partslists
    [partnumbers.csv, partslist.csv]
2023-05-20 Update kicad project for v7
    [filter.kicad_sch, magnum-drum-synth.kicad_sch, output-vca.kicad_sch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]
2023-07-11 Final board tweaks
    [magnum-drum-synth.kicad_pcb, magnum-drum-synth.kicad_sch, output-vca.kicad_sch]
2023-07-15 Generating new gerbers
    [magnum-drum-synth-B_Cu.gbl, magnum-drum-synth-B_Mask.gbs, magnum-drum-synth-B_Silkscreen.gbo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]
2023-07-19 rev06 gerbers
    [magnum-drum-synth-B_Cu.gbl, magnum-drum-synth-B_Mask.gbs, magnum-drum-synth-B_Silkscreen.gbo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]
2024-01-11 Final tweaks
    [magnum-drum-synth.kicad_pcb, magnum-drum-synth.kicad_sch]
2024-01-11 replotting gerbers
    [magnum-drum-synth-B_Cu.gbl, magnum-drum-synth-B_Mask.gbs, magnum-drum-synth-B_Silkscreen.gbo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]

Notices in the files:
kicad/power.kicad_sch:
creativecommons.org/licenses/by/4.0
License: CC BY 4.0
